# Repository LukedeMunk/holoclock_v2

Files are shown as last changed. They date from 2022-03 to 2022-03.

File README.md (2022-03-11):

# HoloClock v2
[Nederlands](README.nl.md)

An ESP32 based improved version of the HoloClock project of [ekaggrat](https://www.thingiverse.com/thing:570797). This code can be used for the [HoloClock v2](https://technicbuilds.munkservices.com/) DIY kit. Everything what you need is in the DIY kit, so it is recommended to buy the kit. If you want to make it without the kit, you need a 3D printer and hardware components. The components needed is listed under `Hardware`. The code is mainly explained in comments, but there is also documentation [here](docs/code_documentation). You can test your own code and use these files as a backup. The software is tested on the following boards:

* ESP32 DEVKIT V1

## Hardware

### Electronics

A list of the needed hardware components is given below. The circuit can be found in the `docs` folder.

* 1x ESP32 DEVKIT V1
* 1x A4988 motorboard
* 1x 28BYJ-48 12V motor
* 1x 12V 2A adapter (3.5mm/1mm DC plug)
* 1x 12V to 5V step down converter (LM7805)
* 1x PCB
* 1x DC022B Panel Mount Connector

### 3D objects

A list of the needed 3D models is given below. The printer which is used to print, is the Creality CR-10S Pro V2. Ultimaker Cura v4.12.1 is used to slice the objects. In the `hardware/3D models` folder, you can find the models.

* 1x `base_1`
* 1x `base_2`
* 2x `big_ring`
* 1x `frame_l`
* 1x `frame_r`
* 1x `gear_center`
* 1x `gear_hour`
* 1x `gear_motor`
* 2x `gear_side`
* 1x `joiner_7mm`
* 1x `joiner_10mm`
* 3x `joiner_13mm`
* 1x `needle_hour`
* 1x `needle_minute`
* 1x `PCB_helper` (Optional)
* 2x `roller_1`
* 2x `roller_2`
* 2x `roller_stopper`
* 2x `spacer_10mm`
* 2x `spacer_14mm`
* 2x `spacer_30mm`
* 2x `spacer_middle`
* 3x `wheel_1`
* 1x `wheel_2`

### Bolts and inserted threads

A list of the bolds and inserted threads is given below.

* 2x `M3 bolt 5mm`
* 1x `M3 bolt 25mm`
* 2x `M3 bold 30mm`
* 6x `M3 bold 40mm`
* 19x `M3 4mmx5mm inserted thread`

## Software

### Prerequisites

The software is written, compiled and uploaded using the Arduino IDE (v1.8.13). You could use the online Arduino IDE or other software, but it is recommended using the version you can download on [this page](https://www.arduino.cc/en/software).

### Deployment

Clone the repository, navigate to the `holoclock_v2/HoloClock` folder and open `holoClock.ino`. Upload to the ESP32. An extended tutorial can be found [here](https://randomnerdtutorials.com/installing-the-esp32-board-in-arduino-ide-windows-instructions/).

Then use [this tool](https://randomnerdtutorials.com/install-esp32-filesystem-uploader-arduino-ide/) to upload the webserver files (.html, .css, etc.) to the ESP32.

Connect to the `Configure clock` network and fill in the password `clock1234`. Go to a browser and search for `192.168.4.1` (or `http://clock`) and connect to a wifi network.
After a reboot, go to a (mobile) browser and search `http://clock`. Here you can control the clock.

## Questions or feedback?

You can submit an issue if you have questions or feedback for this repository. If you are interested in more of my projects, checkout my [GitHub profile](https://github.com/LukedeMunk). If you are interested in hiring me, checkout my [LinkedIn](https://www.linkedin.com/in/luke-de-munk/) or [website](https://www.munkservices.com). Want to buy this product? Visit the [TechnicBuilds](https://technicbuilds.munkservices.com/) website.

## Authors

* **Luke de Munk** - *Head author of software* - [LinkedIn](https://www.linkedin.com/in/luke-de-munk/)
* **ekaggrat** - *Creator of original project* - [ekaggrat](https://www.thingiverse.com/thing:570797)

<!-- ## License

This project is licensed under the MIT License - see the [LICENSE.md](LICENSE.md) file for details -->

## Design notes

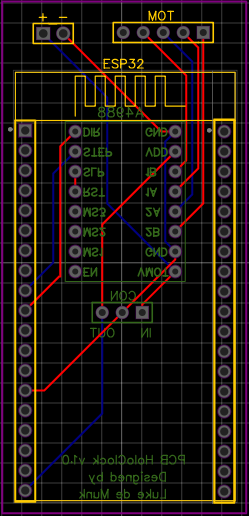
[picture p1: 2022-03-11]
docs/PCB Design.png

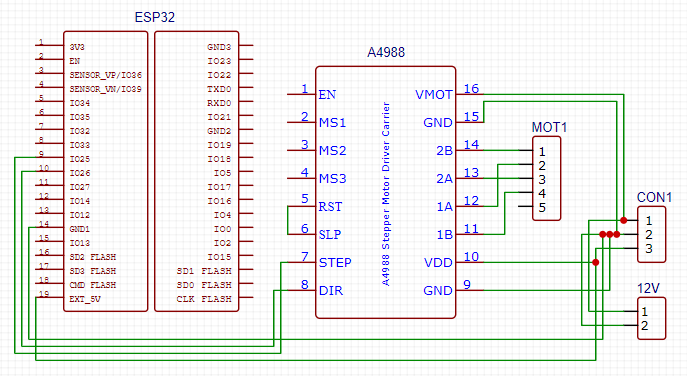
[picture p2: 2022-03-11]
docs/Circuit Diagram.png

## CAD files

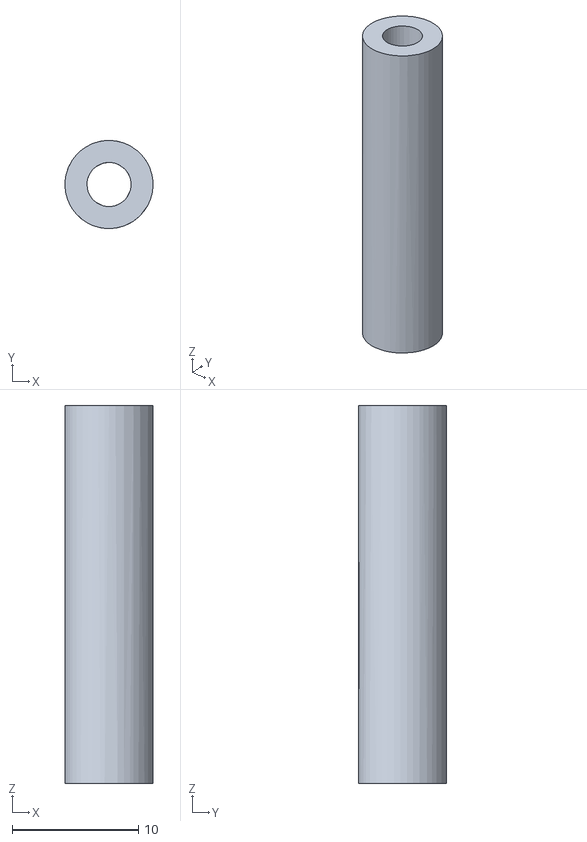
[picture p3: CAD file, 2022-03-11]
hardware/3D models/spacer_30mm.stl
6.98 x 7.00 x 30.0

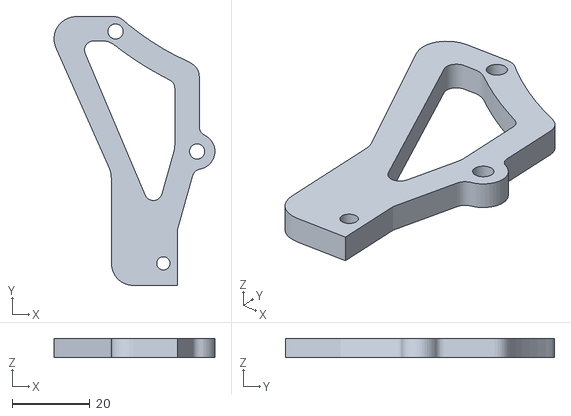
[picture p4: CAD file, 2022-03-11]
hardware/3D models/frame_r.stl
41.4 x 69.2 x 5.00

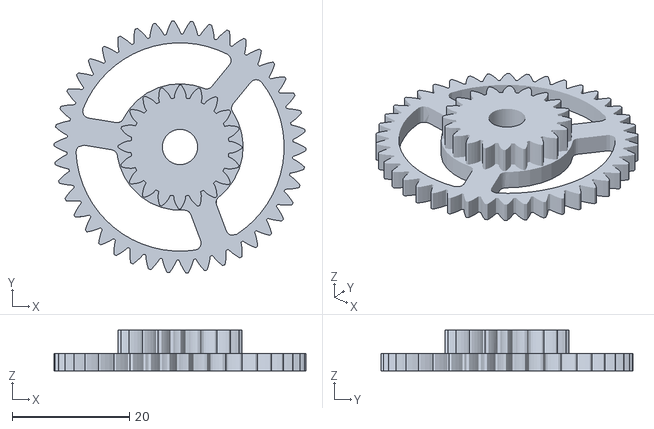
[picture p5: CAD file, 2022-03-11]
hardware/3D models/gear_hour.stl
43.0 x 43.0 x 7.00

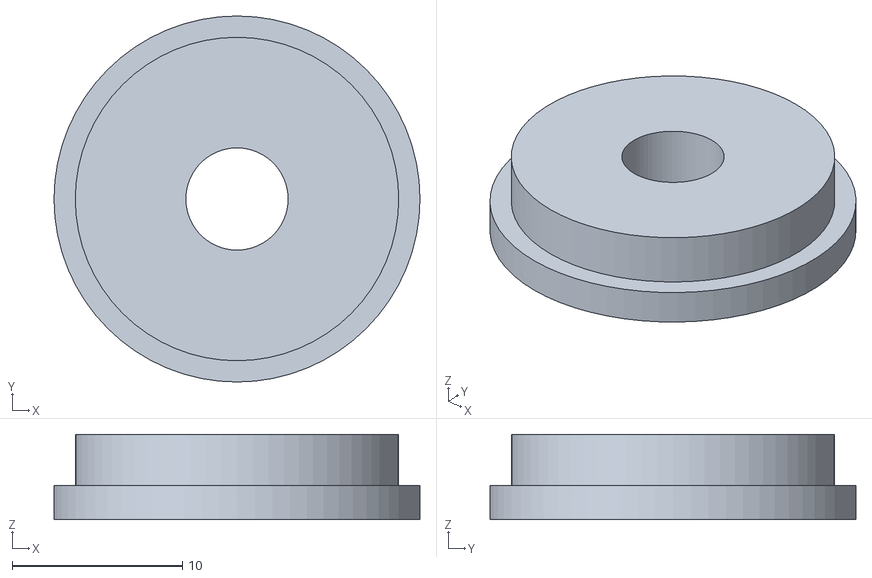
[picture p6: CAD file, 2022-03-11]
hardware/3D models/wheel_1.stl
21.5 x 21.5 x 5.00

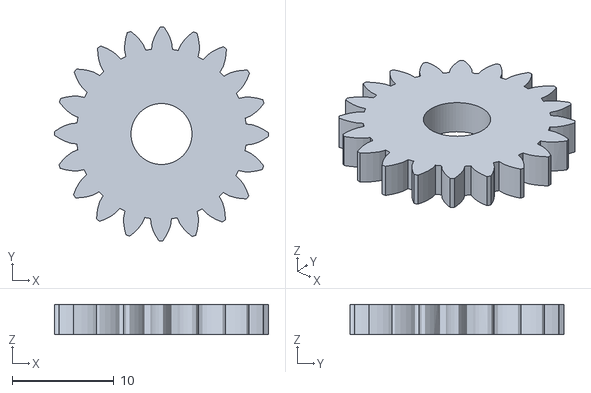
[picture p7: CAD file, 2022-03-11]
hardware/3D models/gear_side.stl
21.1 x 21.1 x 3.00

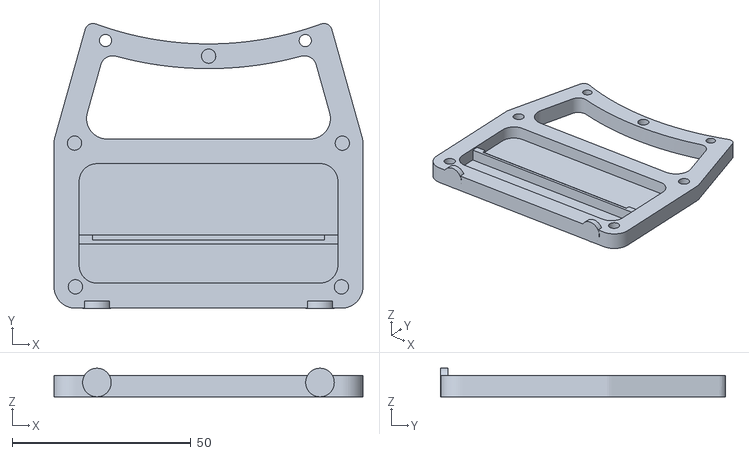
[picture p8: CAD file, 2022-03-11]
hardware/3D models/base_1.stl
86.4 x 79.7 x 8.00

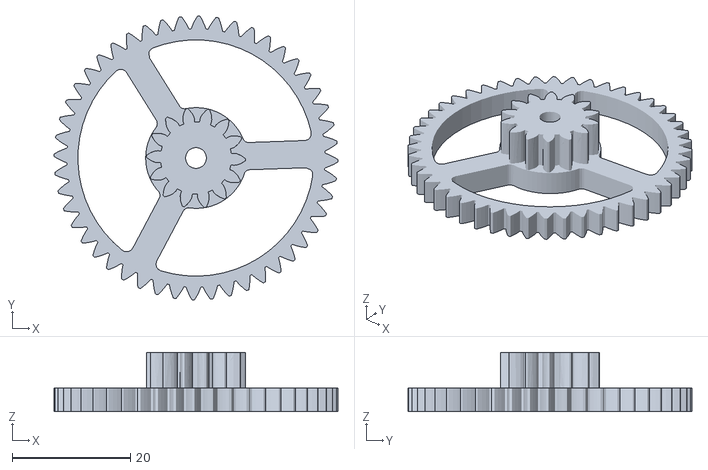
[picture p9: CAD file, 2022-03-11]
hardware/3D models/gear_center.stl
47.9 x 47.9 x 10.0

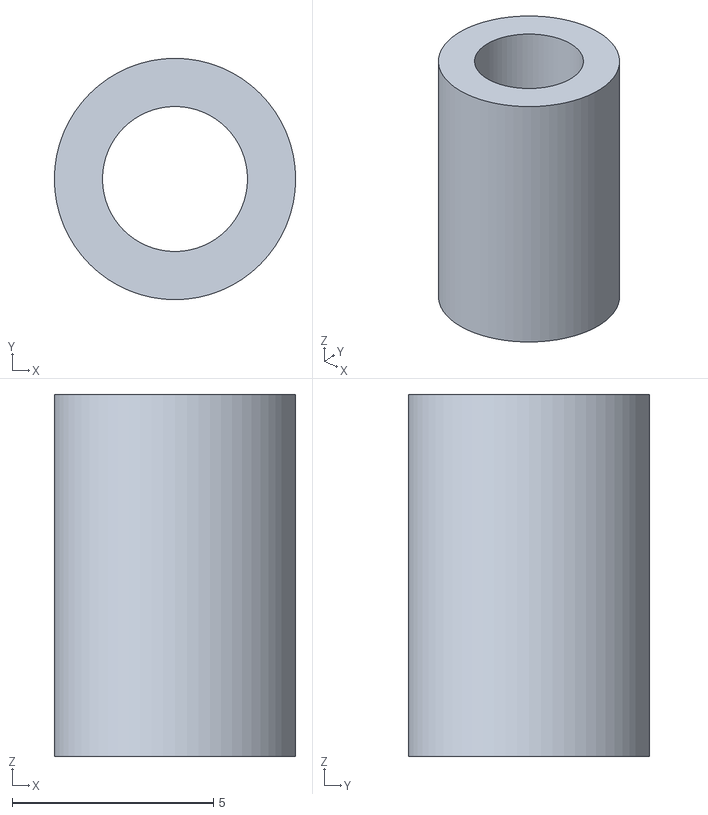
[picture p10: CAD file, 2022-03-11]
hardware/3D models/spacer_middle.stl
6.00 x 6.00 x 9.00

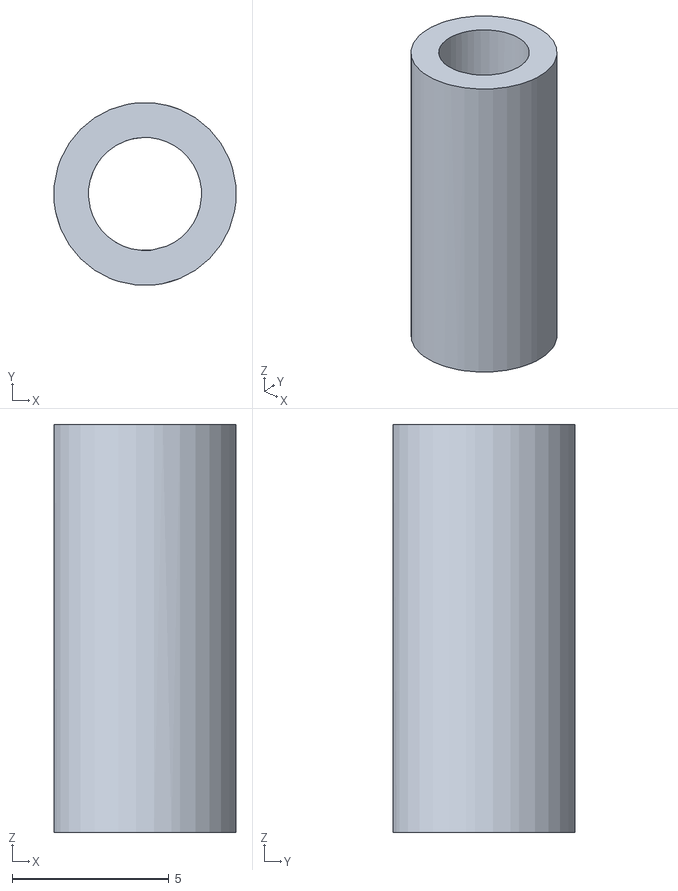
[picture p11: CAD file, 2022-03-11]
hardware/3D models/joiner_13mm.stl
5.79 x 5.80 x 13.0

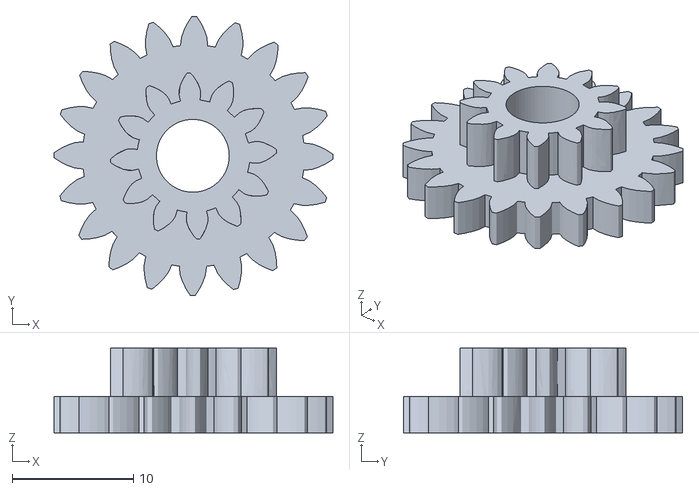
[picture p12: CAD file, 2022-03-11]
hardware/3D models/gear_motor.stl
23.0 x 23.0 x 7.00

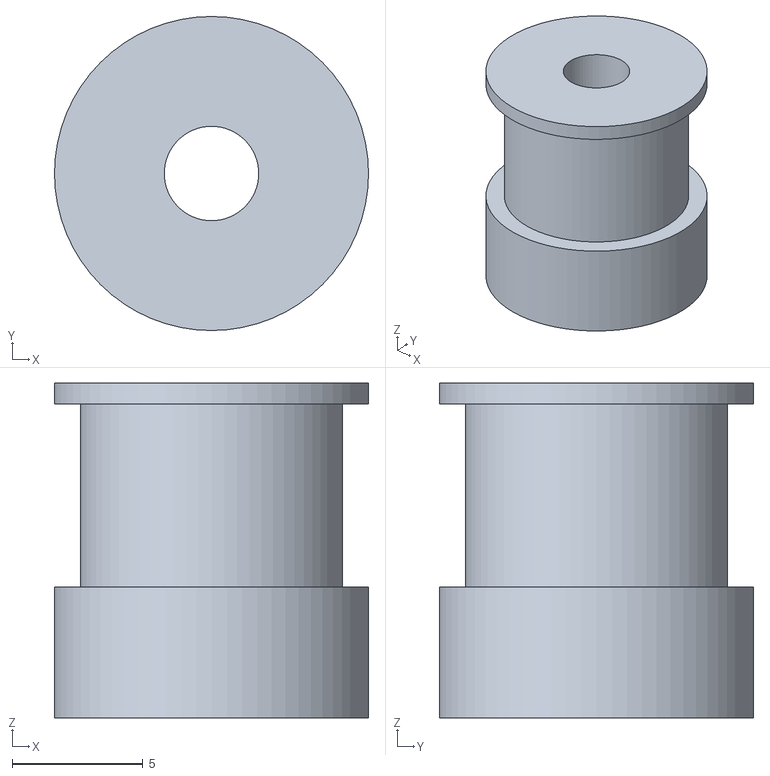
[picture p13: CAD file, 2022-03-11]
hardware/3D models/roller_1.stl
12.0 x 12.0 x 12.8

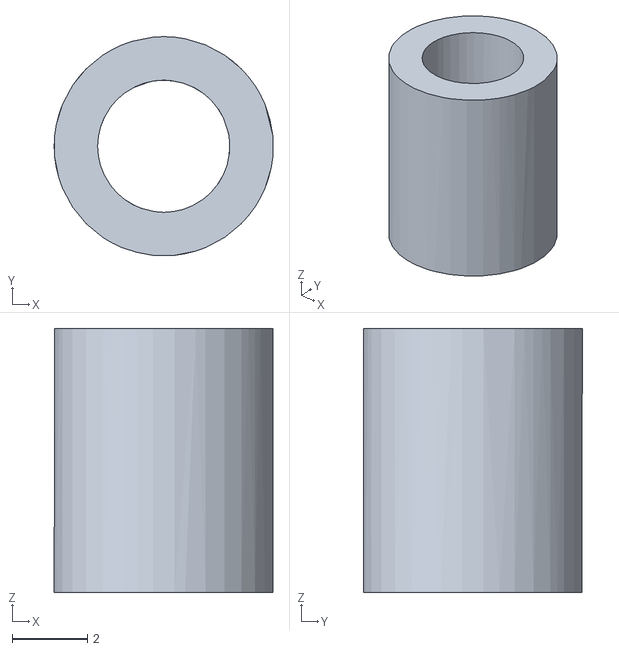
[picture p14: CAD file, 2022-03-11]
hardware/3D models/joiner_7mm.stl
5.80 x 5.80 x 7.00

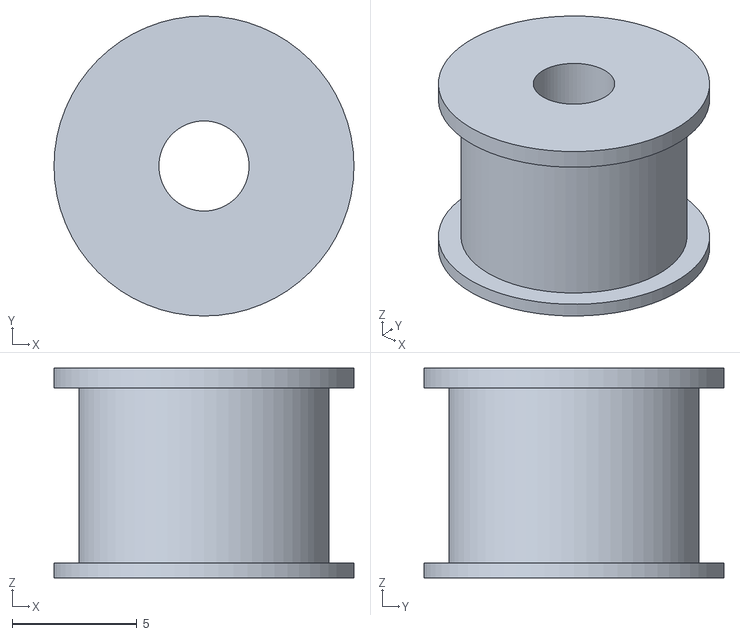
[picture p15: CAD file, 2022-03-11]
hardware/3D models/roller_2.stl
12.0 x 12.0 x 8.40

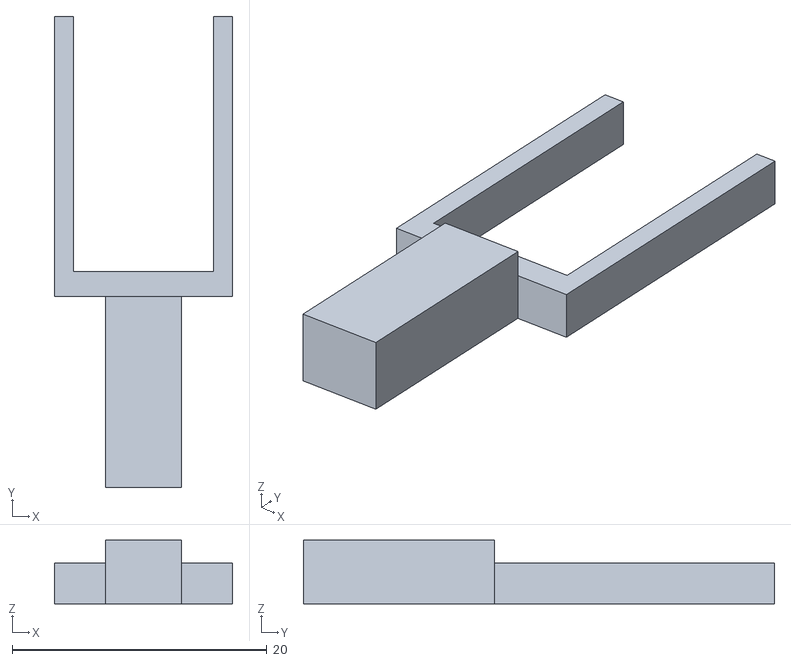
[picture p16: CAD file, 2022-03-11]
hardware/3D models/PCB_helper.stl
14.0 x 37.0 x 5.00

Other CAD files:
hardware/3D models/needle_minute.stl
hardware/3D models/wheel_2.stl
hardware/3D models/needle_hour.stl
hardware/3D models/joiner_10mm.stl
hardware/3D models/base_2.stl
hardware/3D models/big_ring.stl
hardware/3D models/frame_l.stl
hardware/3D models/roller_stopper.stl
hardware/3D models/spacer_10mm.stl
hardware/3D models/spacer_14mm.stl

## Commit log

2022-03-11 Create Circuit Diagram.png
2022-03-11 3D models upload
    [PCB_helper.stl, base_1.stl, base_1_max.stl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]
2022-03-11 Create PCB Design.png
